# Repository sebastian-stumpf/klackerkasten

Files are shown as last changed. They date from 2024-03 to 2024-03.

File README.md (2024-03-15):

# Klackerkasten

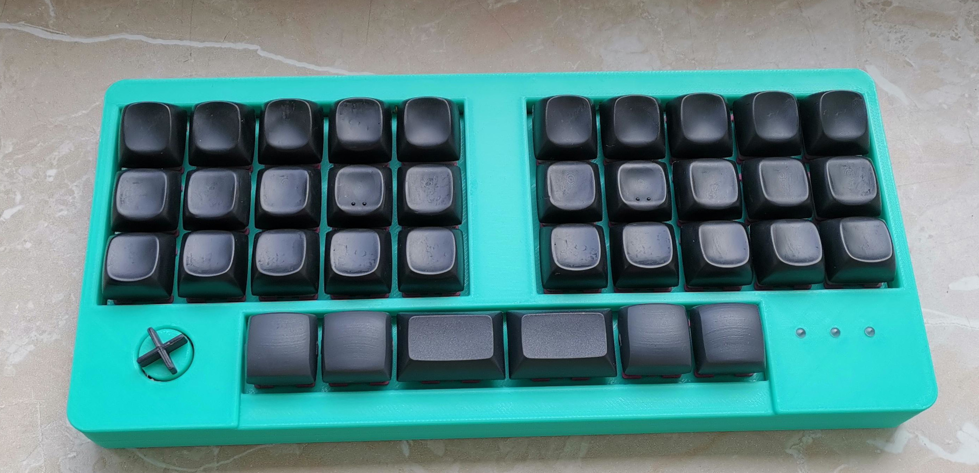
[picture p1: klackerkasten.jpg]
klackerkasten


Note: If you are not hand solerding the components then triple check the component orientation. I went
the PCBA route with JLC and there were two rotated components.

# Acknowledgments

- Weteor for his amazing BrkOut which was a big inspiration.
- NcKiser for the STM32F072\_template which helped me a lot for this project.
- The mad crowd of the Clack Tales discord server. Thanks for answering all my endless questions!

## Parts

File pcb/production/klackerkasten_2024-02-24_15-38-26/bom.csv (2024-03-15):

Designator | Footprint | Quantity | Value | LCSC Part #
BOOT1, RST1 | SW_SPST_TL3342 | 2 | SW_SPST | C318884
C1, C3, C4, C5, C6, C7, C8 | 402 | 7 | 100nF | C307331
C10, C9 | 402 | 2 | 1uF | C52923
C2 | 603 | 1 | 10uF | C19702
D1, D10, D11, D12, D13, D14, D15, D16, D17, D18, D19, D2, D20, D21, D22, D23, D24, D25, D26, D27, D28, D29, D3, D30, D31, D32, D33, D34, D35, D36, D4, D5, D6, D7, D8, D9 | D_SOD-123 | 36 | 1N4148W | C81598
F1 | 1206 | 1 | 500mA | C369160
J1 | USB_C_Receptacle_HRO_TYPE-C-31-M-12 | 1 | USB_C_Receptacle_USB2.0 | C165948
R1, R2, R3, R4 | 402 | 4 | 5.1k | C25905
U1 | LQFP-48_7x7mm_P0.5mm | 1 | STM32F072CBT6 | C81720
U2 | SOT-143 | 1 | PRTR5V0U2X | C2827688
U3 | SOT-23 | 1 | XC6206PxxxMR-Regulator_Linear | C5446

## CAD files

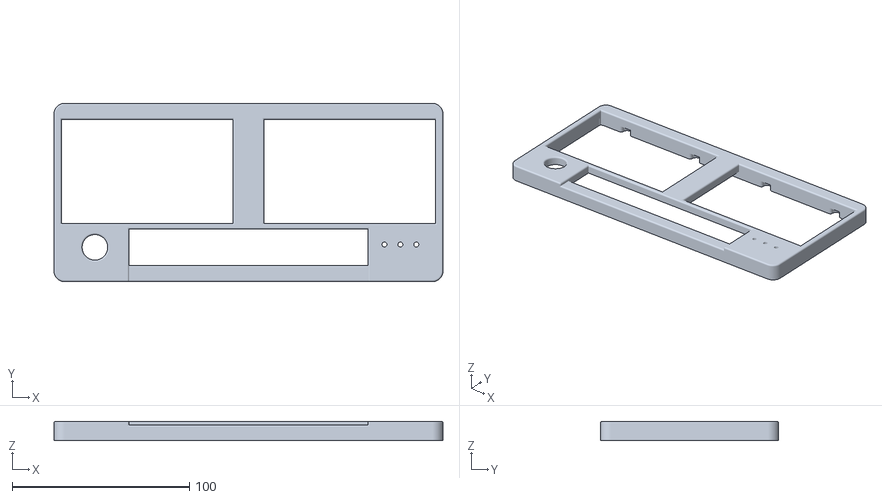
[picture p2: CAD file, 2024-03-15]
case/case-top.stl
219.6 x 100.7 x 11.0

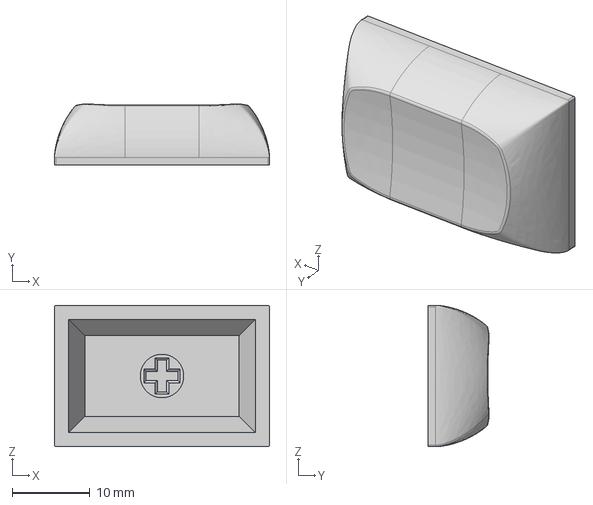
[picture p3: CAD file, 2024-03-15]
models/DSA 1.5u.step
27.7 x 7.91 x 18.2 mm

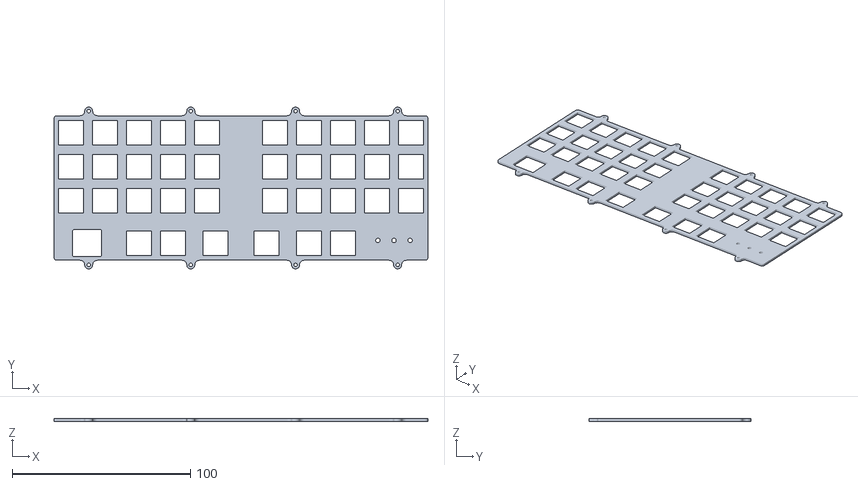
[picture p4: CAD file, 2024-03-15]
case/case-plate.stl
209.6 x 90.7 x 1.50

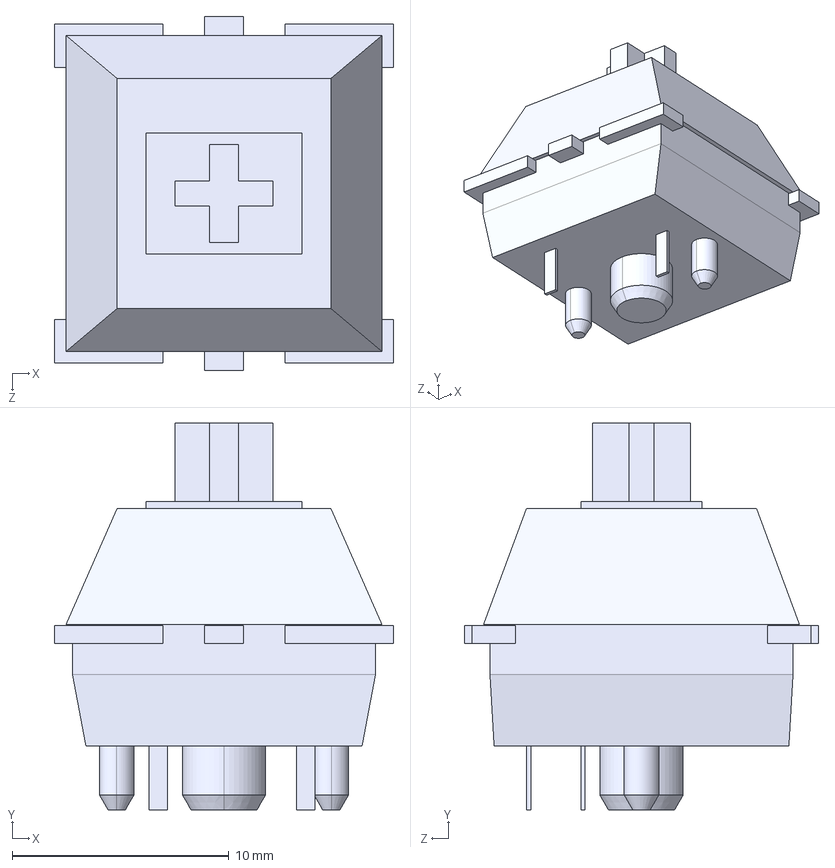
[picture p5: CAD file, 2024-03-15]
models/cherry mx.STEP
15.6 x 17.9 x 16.3 mm

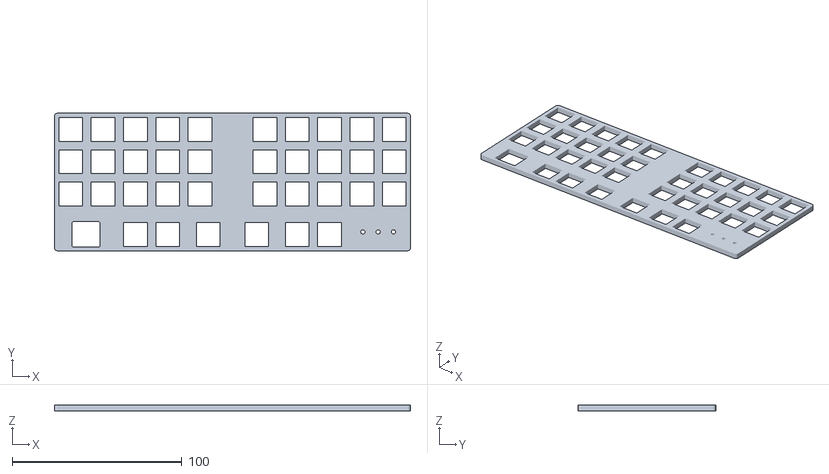
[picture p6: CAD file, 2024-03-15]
case/case-foam.stl
209.6 x 81.0 x 3.50

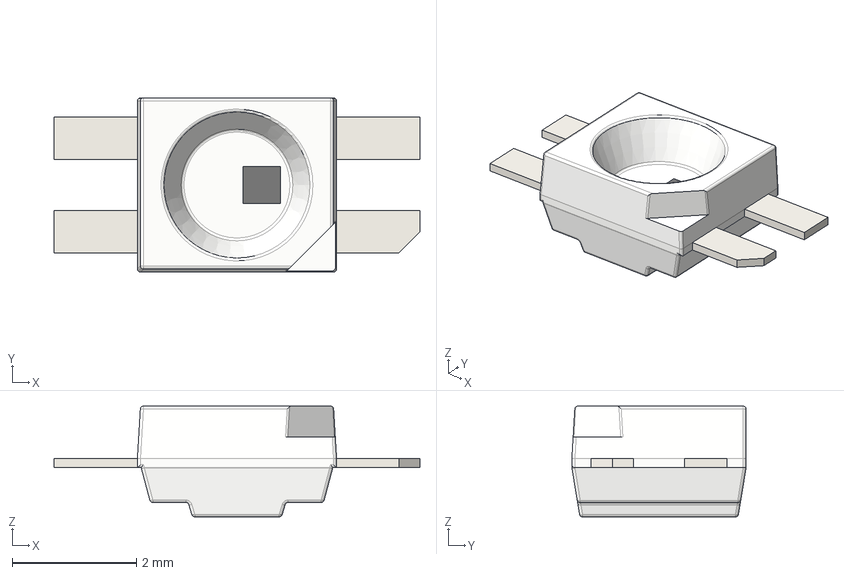
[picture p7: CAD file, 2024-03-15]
models/LED_SK6812MINI-E.step
5.88 x 2.80 x 1.78 mm

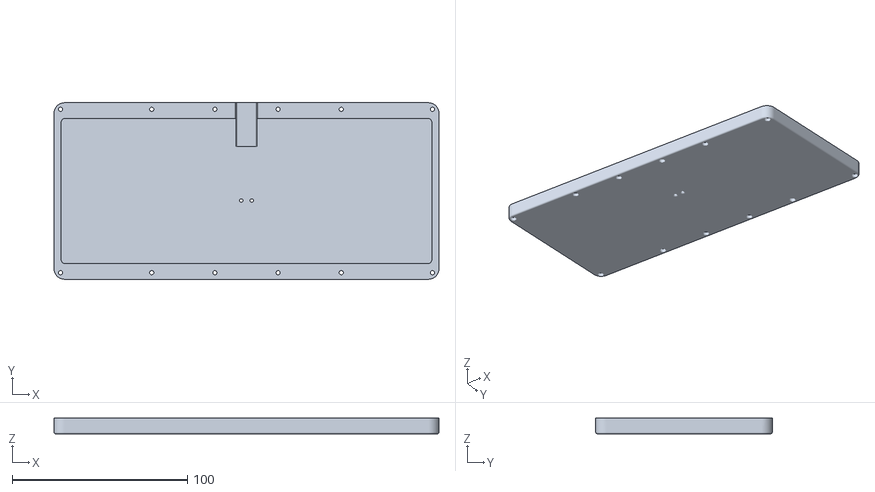
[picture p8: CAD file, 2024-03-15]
case/case-bottom.stl
219.6 x 100.7 x 9.00

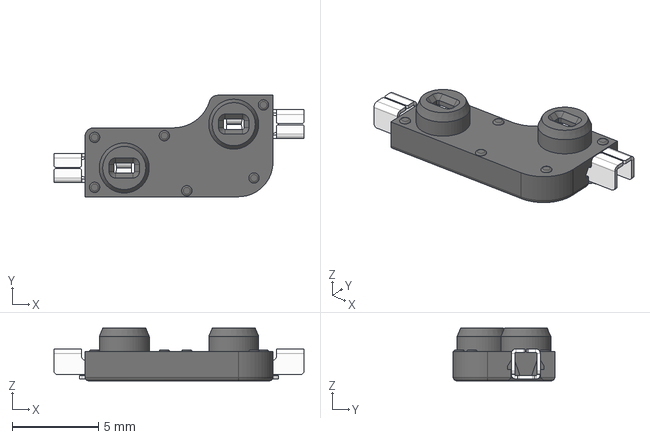
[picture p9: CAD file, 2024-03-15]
models/HS_Kailh_MX.step
14.5 x 5.89 x 3.05 mm
Contact x 2

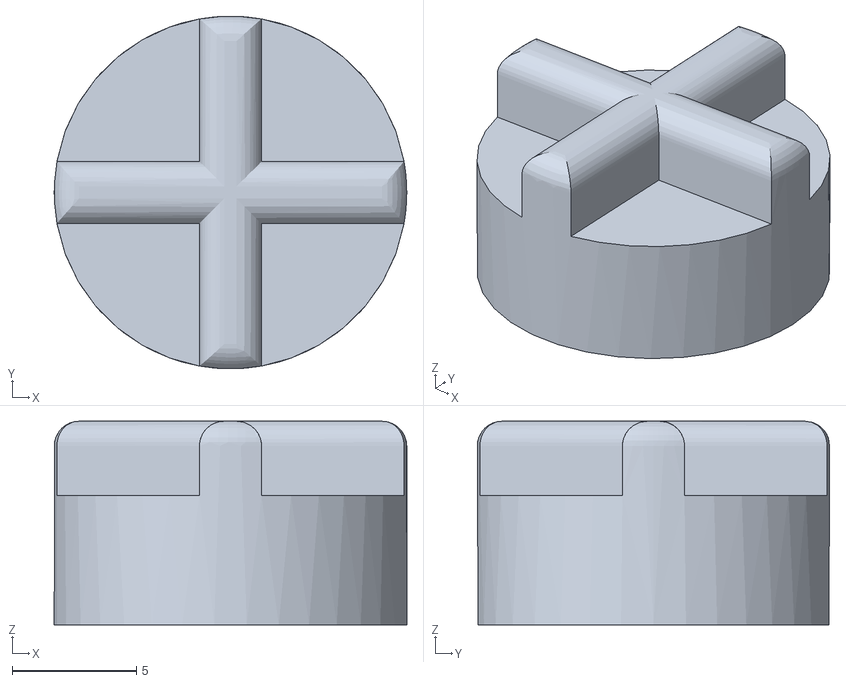
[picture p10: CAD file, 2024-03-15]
case/case-knob.stl
14.2 x 14.2 x 8.20

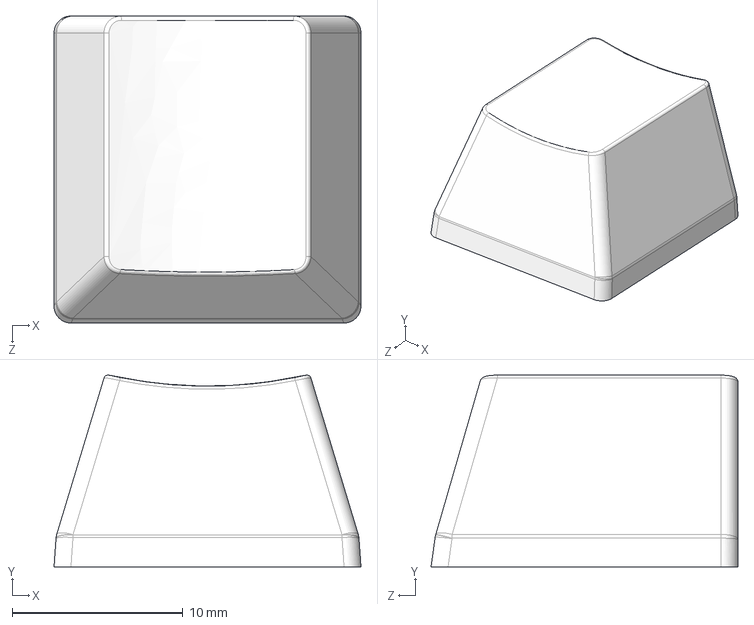
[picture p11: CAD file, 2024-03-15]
models/mx_kecap.step
18.0 x 11.3 x 18.0 mm

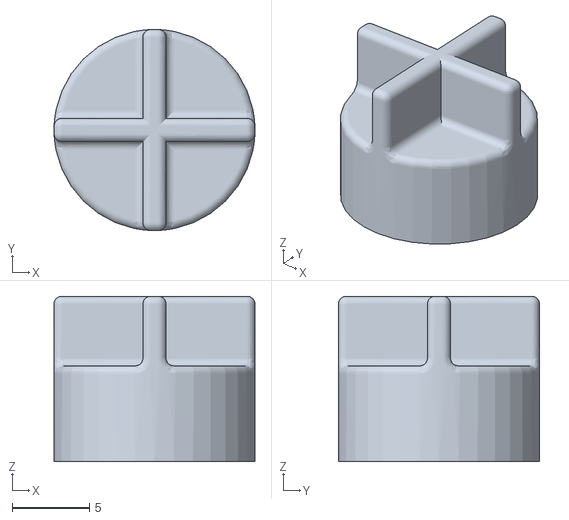
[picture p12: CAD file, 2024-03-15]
case/case-alt-knob.stl
13.0 x 13.0 x 10.7

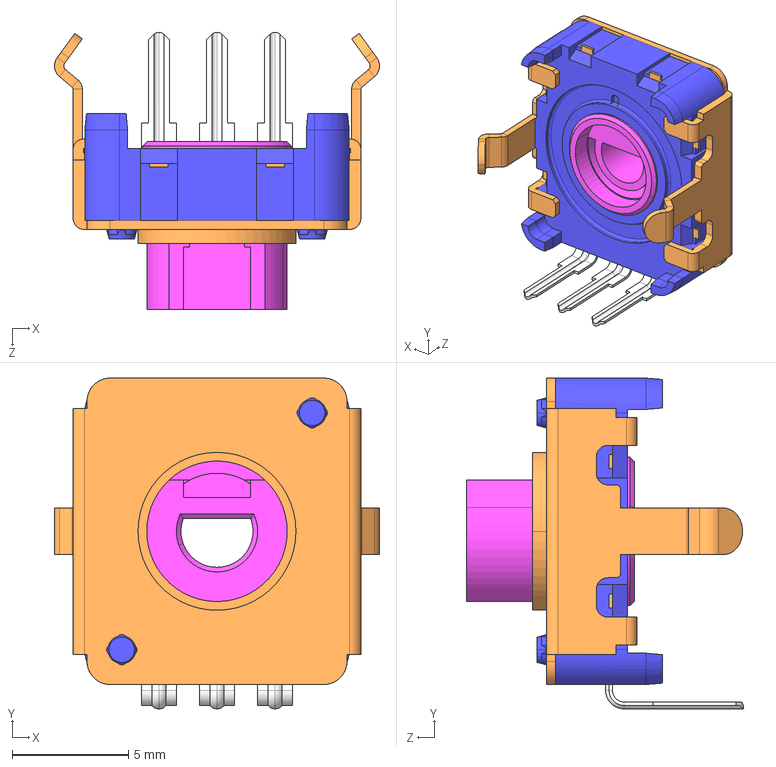
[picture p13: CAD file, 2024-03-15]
models/EC12E-085.step
14.0 x 14.3 x 11.9 mm

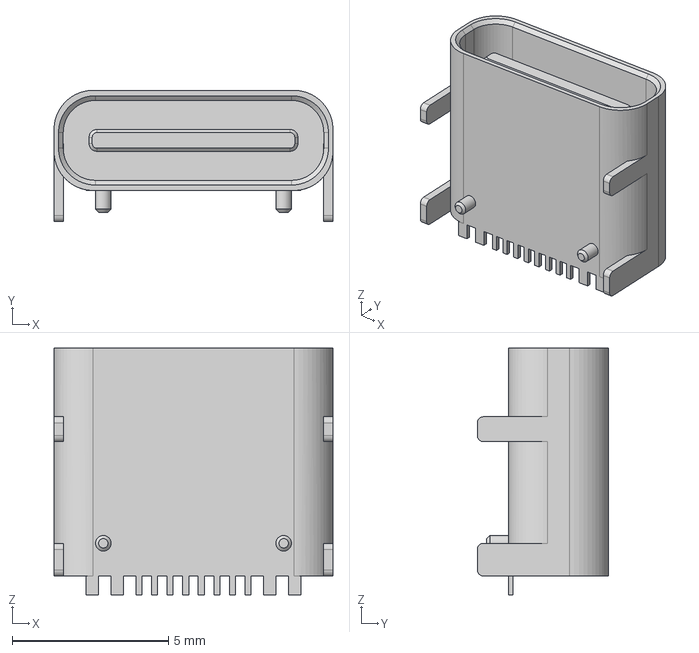
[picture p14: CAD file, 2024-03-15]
models/HRO TYPE-C-31-M-12.step
8.94 x 4.21 x 7.90 mm

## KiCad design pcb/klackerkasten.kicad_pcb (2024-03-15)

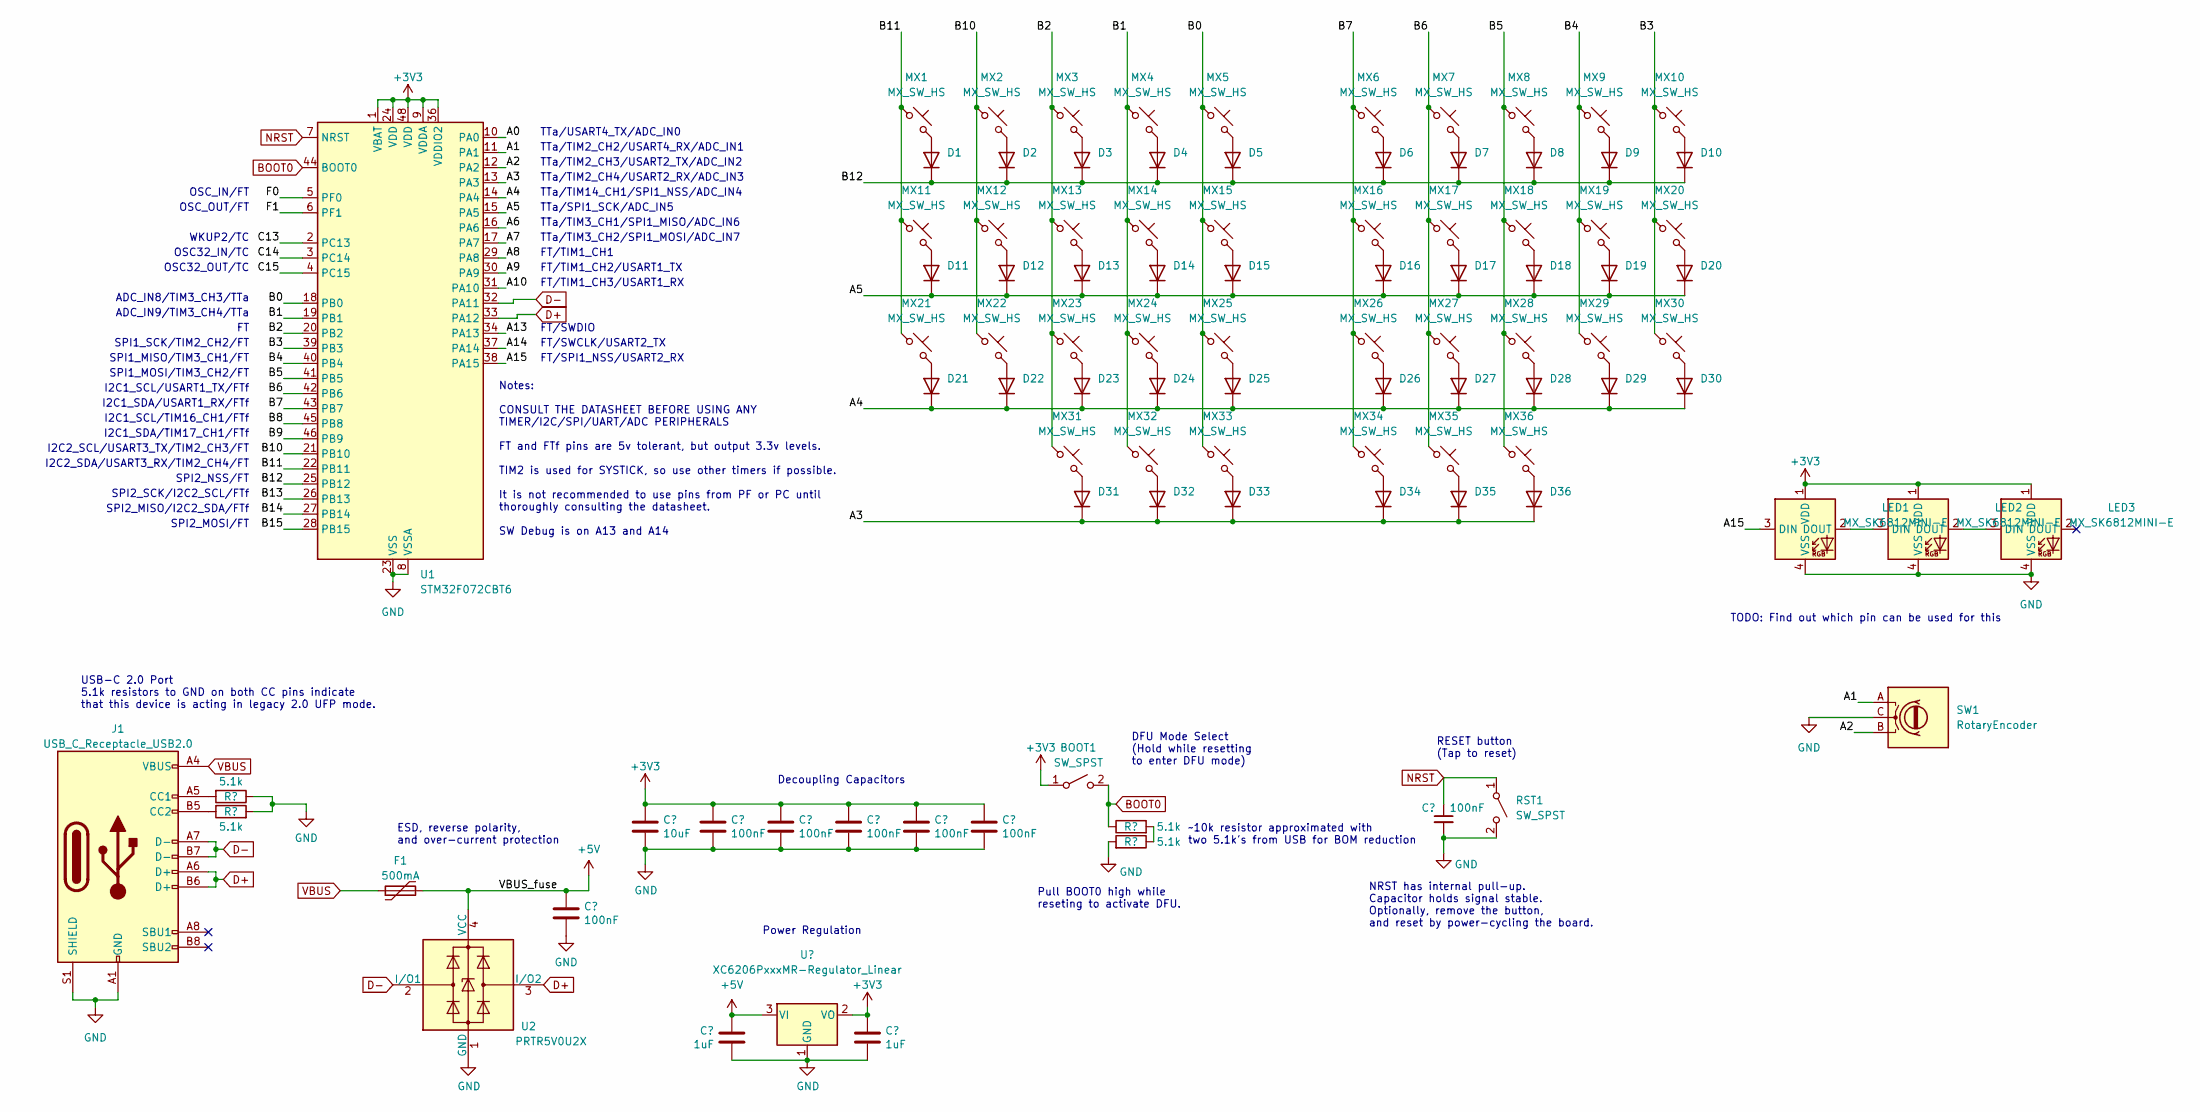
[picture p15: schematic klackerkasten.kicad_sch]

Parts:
BOOT1: SW_SPST; SW_SPST_TL3342; LCSC C318884
C1, C3, C4, C5, C6, C7, C8: 100nF; C_0402_1005Metric; LCSC C307331
C2: 10uF; C_0603_1608Metric; LCSC C307331
C9, C10: 1uF; C_0402_1005Metric; LCSC C307331
D1, D2, D3, D4, D5, D6, D7, D8, D9, D10, D11, D12, D13, D14, D15, D16, D17, D18, D19, D20, D21, D22, D23, D24, D25, D26, D27, D28, D29, D30, D31, D32, D33, D34, D35, D36: 1N4148W; D_SOD-123; LCSC C81598
F1: 500mA; Fuse_1206_3216Metric; LCSC C135341
J1: USB_C_Receptacle_USB2.0; USB_C_Receptacle_HRO_TYPE-C-31-M-12; JlcRotOffset 180
LED1, LED2, LED3: MX_SK6812MINI-E; LED_6028R; LCSC C5149201
MX1, MX2, MX3, MX4, MX5, MX6, MX7, MX8, MX9, MX10, MX11, MX12, MX13, MX14, MX15, MX16, MX17, MX18, MX19, MX20, MX21, MX22, MX23, MX24, MX25, MX26, MX27, MX28, MX29, MX30, MX31, MX32, MX35, MX36: MX_SW_HS; SW_MX_HS_CPG151101S11_1u; LCSC C5156480
MX33, MX34: MX_SW_HS; SW_MX_HS_CPG151101S11_1.5u; LCSC C5156480
R1, R2, R3, R4: 5.1k; R_0402_1005Metric; LCSC C25905
RST1: SW_SPST; SW_SPST_TL3342; LCSC C318884
SW1: RotaryEncoder; RotaryEncoder_Alps_EC12E_Vertical_H20mm
U1: STM32F072CBT6; LQFP-48_7x7mm_P0.5mm; JlcRotOffset 90
U2: PRTR5V0U2X; SOT-143; LCSC C2827688
U3: XC6206PxxxMR-Regulator_Linear; SOT-23; LCSC C5446

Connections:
+3V3: BOOT1.1 (A), C2.1, C3.1, C4.1, C5.1, C6.1, C7.1, C10.1, LED1.1 (VDD), LED2.1 (VDD), LED3.1 (VDD), U1.1 (VBAT), U1.9 (VDDA), U1.24 (VDD), U1.36 (VDDIO2), U1.48 (VDD), U3.2 (VO)
+5V: C8.1, C9.1, F1.2, U2.4 (VCC), U3.3 (VI)
/A0: U1.10 (PA0)
/A1: SW1.A, U1.11 (PA1)
/A2: SW1.B, U1.12 (PA2)
/A3: D31.1 (K), D32.1 (K), D33.1 (K), D34.1 (K), D35.1 (K), D36.1 (K), U1.13 (PA3)
/A4: D21.1 (K), D22.1 (K), D23.1 (K), D24.1 (K), D25.1 (K), D26.1 (K), D27.1 (K), D28.1 (K), D29.1 (K), D30.1 (K), U1.14 (PA4)
/A5: D11.1 (K), D12.1 (K), D13.1 (K), D14.1 (K), D15.1 (K), D16.1 (K), D17.1 (K), D18.1 (K), D19.1 (K), D20.1 (K), U1.15 (PA5)
/A6: U1.16 (PA6)
/A7: U1.17 (PA7)
/A8: U1.29 (PA8)
/A9: U1.30 (PA9)
/A10: U1.31 (PA10)
/A13: U1.34 (PA13)
/A14: U1.37 (PA14)
/A15: LED1.3 (DIN), U1.38 (PA15)
/B0: MX5.1, MX15.1, MX25.1, MX33.1, U1.18 (PB0)
/B1: MX4.1, MX14.1, MX24.1, MX32.1, U1.19 (PB1)
/B2: MX3.1, MX13.1, MX23.1, MX31.1, U1.20 (PB2)
/B3: MX10.1, MX20.1, MX30.1, U1.39 (PB3)
/B4: MX9.1, MX19.1, MX29.1, U1.40 (PB4)
/B5: MX8.1, MX18.1, MX28.1, MX36.1, U1.41 (PB5)
/B6: MX7.1, MX17.1, MX27.1, MX35.1, U1.42 (PB6)
/B7: MX6.1, MX16.1, MX26.1, MX34.1, U1.43 (PB7)
/B8: U1.45 (PB8)
/B9: U1.46 (PB9)
/B10: MX2.1, MX12.1, MX22.1, U1.21 (PB10)
/B11: MX1.1, MX11.1, MX21.1, U1.22 (PB11)
/B12: D1.1 (K), D2.1 (K), D3.1 (K), D4.1 (K), D5.1 (K), D6.1 (K), D7.1 (K), D8.1 (K), D9.1 (K), D10.1 (K), U1.25 (PB12)
/B13: U1.26 (PB13)
/B14: U1.27 (PB14)
/B15: U1.28 (PB15)
/C13: U1.2 (PC13)
/C14: U1.3 (PC14)
/C15: U1.4 (PC15)
/F0: U1.5 (PF0)
/F1: U1.6 (PF1)
BOOT0: BOOT1.2 (B), R3.1, U1.44 (BOOT0)
D+: J1.A6 (D+), J1.B6 (D+), U1.33 (PA12), U2.3 (I/O2)
D-: J1.A7 (D-), J1.B7 (D-), U1.32 (PA11), U2.2 (I/O1)
GND: C1.2, C2.2, C3.2, C4.2, C5.2, C6.2, C7.2, C8.2, C9.2, C10.2, J1.A1 (GND), J1.A12 (GND), J1.B1 (GND), J1.B12 (GND), J1.S1 (SHIELD), LED1.4 (VSS), LED2.4 (VSS), LED3.4 (VSS), R1.1, R2.2, R4.2, RST1.2 (B), SW1.C, U1.8 (VSSA), U1.23 (VSS), U1.35 (VSS), U1.47 (VSS), U2.1 (GND), U3.1 (GND)
NRST: C1.1, RST1.1 (A), U1.7 (NRST)
unnamed: D1.2 (A), MX1.2
unnamed: D2.2 (A), MX2.2
unnamed: D3.2 (A), MX3.2
unnamed: D4.2 (A), MX4.2
unnamed: D5.2 (A), MX5.2
unnamed: D6.2 (A), MX6.2
unnamed: D7.2 (A), MX7.2
unnamed: D8.2 (A), MX8.2
unnamed: D9.2 (A), MX9.2
unnamed: D10.2 (A), MX10.2
unnamed: D11.2 (A), MX11.2
unnamed: D12.2 (A), MX12.2
unnamed: D13.2 (A), MX13.2
unnamed: D14.2 (A), MX14.2
unnamed: D15.2 (A), MX15.2
unnamed: D16.2 (A), MX16.2
unnamed: D17.2 (A), MX17.2
unnamed: D18.2 (A), MX18.2
unnamed: D19.2 (A), MX19.2
unnamed: D20.2 (A), MX20.2
unnamed: D21.2 (A), MX21.2
unnamed: D22.2 (A), MX22.2
unnamed: D23.2 (A), MX23.2
unnamed: D24.2 (A), MX24.2
unnamed: D25.2 (A), MX25.2
unnamed: D26.2 (A), MX26.2
unnamed: D27.2 (A), MX27.2
unnamed: D28.2 (A), MX28.2
unnamed: D29.2 (A), MX29.2
unnamed: D30.2 (A), MX30.2
unnamed: D31.2 (A), MX31.2
unnamed: D32.2 (A), MX32.2
unnamed: D33.2 (A), MX33.2
unnamed: D34.2 (A), MX34.2
unnamed: D35.2 (A), MX35.2
unnamed: D36.2 (A), MX36.2
unnamed: J1.A5 (CC1), R1.2
unnamed: J1.B5 (CC2), R2.1
unnamed: LED1.2 (DOUT), LED2.3 (DIN)
unnamed: LED2.2 (DOUT), LED3.3 (DIN)
unnamed: R3.2, R4.1
VBUS: F1.1, J1.A4 (VBUS), J1.A9 (VBUS), J1.B4 (VBUS), J1.B9 (VBUS)

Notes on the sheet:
SPI1_SCK/TIM2_CH2/FT
FT/TIM1_CH1
FT/TIM1_CH3/USART1_RX
SPI2_NSS/FT
Notes: CONSULT THE DATASHEET BEFORE USING ANY TIMER/I2C/SPI/UART/ADC PERIPHERALS FT and FTf pins are 5v tolerant, but output 3.3v levels. TIM2 is used for SYSTICK, so use other timers if possible. It is not recommended to use pins from PF or PC until thoroughly consulting the datasheet. SW Debug is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
TTa/TIM2_CH4/USART2_RX/ADC_IN3
NRST has internal pull-up. Capacitor holds signal stable. Optionally, remove the button, and reset by power-cycling the board.
FT/SWDIO
Decoupling Capacitors
SPI1_MOSI/TIM3_CH2/FT
ADC_IN9/TIM3_CH4/TTa
I2C2_SCL/USART3_TX/TIM2_CH3/FT
SPI2_MISO/I2C2_SDA/FTf
FT/SWCLK/USART2_TX
I2C1_SCL/TIM16_CH1/FTf
~10k resistor approximated with two 5.1k's from USB for BOM reduction
TTa/TIM2_CH2/USART4_RX/ADC_IN1
USB-C 2.0 Port 5.1k resistors to GND on both CC pins indicate that this device is acting in legacy 2.0 UFP mode.
TTa/TIM2_CH3/USART2_TX/ADC_IN2
OSC_IN/FT
DFU Mode Select (Hold while resetting to enter DFU mode)
WKUP2/TC
I2C2_SDA/USART3_RX/TIM2_CH4/FT
ADC_IN8/TIM3_CH3/TTa
RESET button (Tap to reset)
Pull BOOT0 high while reseting to activate DFU.
I2C1_SDA/TIM17_CH1/FTf
TTa/SPI1_SCK/ADC_IN5
TTa/TIM3_CH1/SPI1_MISO/ADC_IN6
TTa/TIM3_CH2/SPI1_MOSI/ADC_IN7
OSC32_OUT/TC
FT/SPI1_NSS/USART2_RX
SPI1_MISO/TIM3_CH1/FT
OSC32_IN/TC
TODO: Find out which pin can be used for this
TTa/TIM14_CH1/SPI1_NSS/ADC_IN4
I2C1_SDA/USART1_RX/FTf
SPI2_MOSI/FT
FT/TIM1_CH2/USART1_TX
Power Regulation

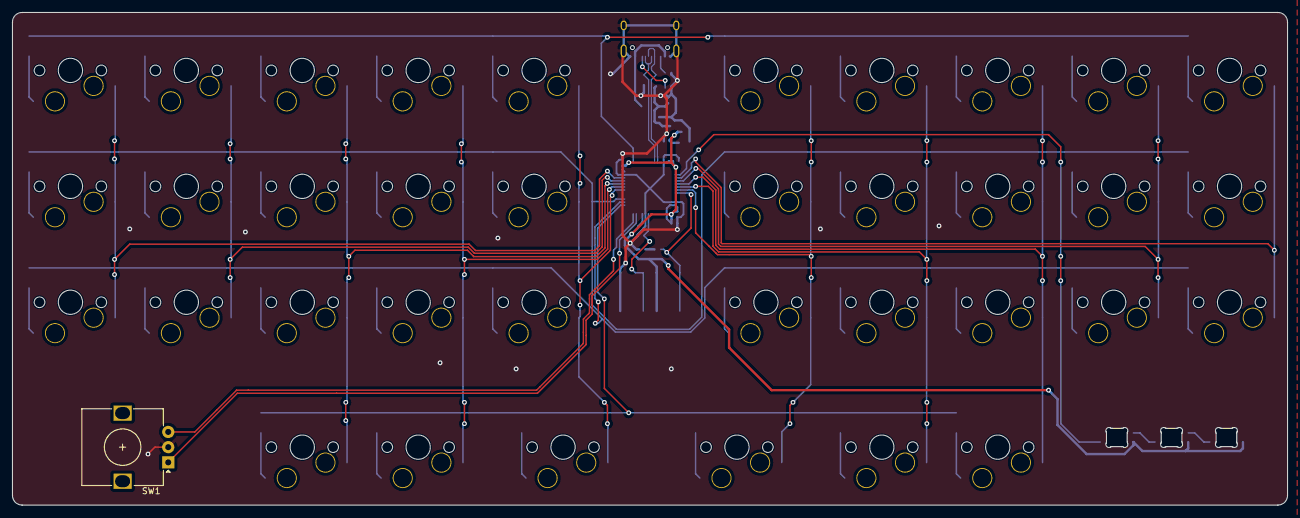
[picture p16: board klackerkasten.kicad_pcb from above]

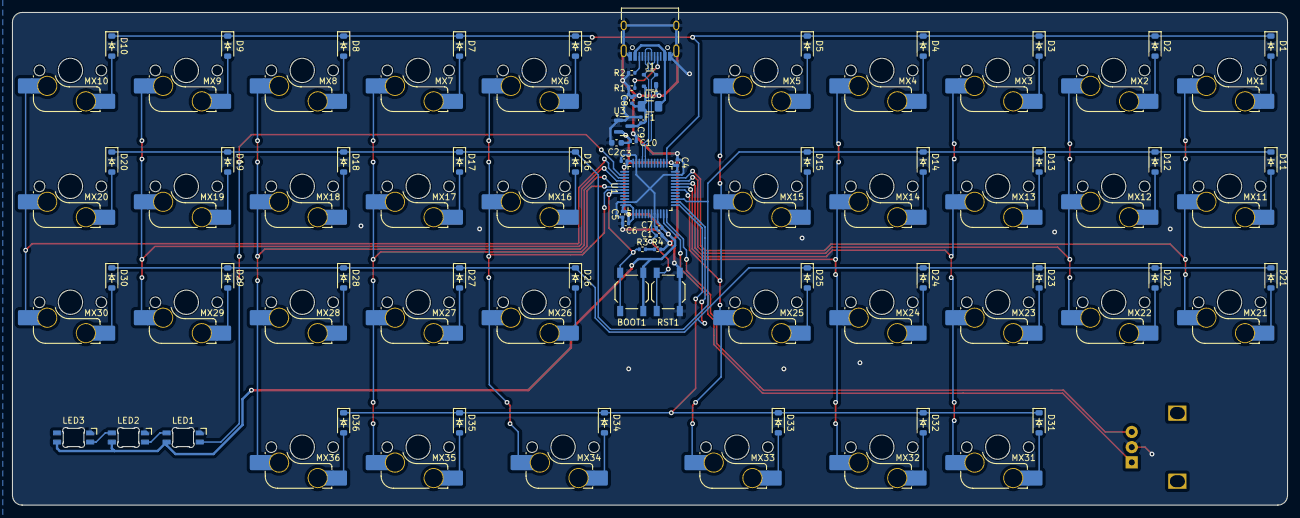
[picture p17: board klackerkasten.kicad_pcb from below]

Board: 2 copper layers, 209.5 x 81.0 mm, 97 parts (96 on the bottom side), 66 nets.
